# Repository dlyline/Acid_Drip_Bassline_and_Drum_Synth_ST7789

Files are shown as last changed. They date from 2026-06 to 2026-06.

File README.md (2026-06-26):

# Acid Drip - Bassline Synth & Drum Machine

<p align="center">
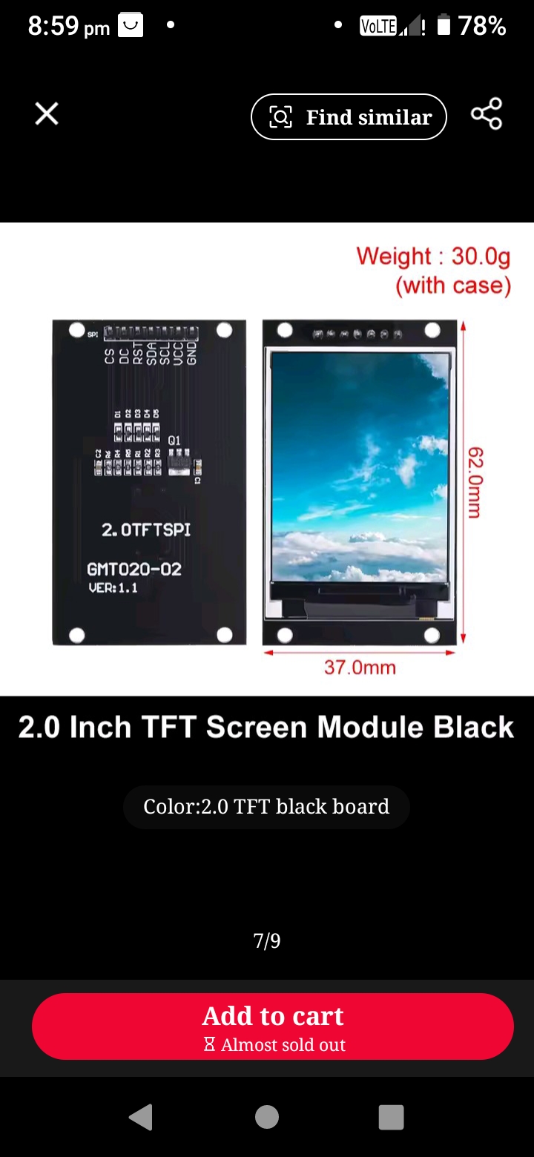
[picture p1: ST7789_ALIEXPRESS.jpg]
TFT
  
  &nbsp;
  DIY
</p>

Youtube Video (click the image) - Acid Drip Demo (https://youtu.be/anotb2mvv04) 

An RP2040-based acid bassline synthesizer and drum machine built on the Mozzi audio library. Two instruments in one device, a 16-step acid sequencer and a 16-pattern drum groove box running simultaneously on dual cores with a 320x240 ILI9341 TFT display and 16 Cherry MX pads.

NOTE: the images of the synth are V1. V2 is what I have provided in this repo and looks a little different (extra pot for mix added)

  

<p align="center">
  Acid Drip - angle view on cyan
  &nbsp;
  Acid Drip - front view on orange
  &nbsp;
  Acid Drip - perspective view on green
</p>

---

## Hardware

| Component | Detail |
|---|---|
| MCU | RP2040 (Raspberry Pi Pico or equivalent) |
| Display | ILI9341 320x240 TFT |
| Pads | 16x Cherry MX switches (2 rows of 8) |
| Pots | 3x analog (CUT, RES, DECAY) |
| Audio out (acid) | GP15 -> 100R + 10nF RC filter -> 3.5mm jack |
| Audio out (drums) | GP2 -> 470R resistor -> 3.5mm jack |
| Sync in | GP2 (hardware SPDT switch selects drum audio OR sync input) |

### Wiring

```
TFT   : SCK=GP6  SDA=GP7  RST=GP8  DC=GP10  CS=GP13
Pots  : CUT=GP26  RES=GP28  DCY=GP27
Sync  : IN=GP2
Audio : Acid=GP15   Drums=GP2

Top row pads (steps 1-8):
  GP14=pad1  GP12=pad2  GP11=pad3  GP16=pad4
  GP17=pad5  GP19=pad6  GP20=pad7  GP21=pad8

Bottom row pads (steps 9-16 / FUNC select):
  GP0=pad9   GP1=pad10  GP3=pad11  GP4=pad12
  GP5=pad13  GP9=pad14  GP18=pad15 GP22=pad16
```

---

## Dependencies

Install via Arduino Library Manager:

- **Mozzi** (audio synthesis engine)
- **Adafruit GFX**
- **Adafruit ILI9341**

Board package: **Raspberry Pi Pico/RP2040** (Earle Philhower core)

---

## Files

| File | Description |
|---|---|
| `Acid_Drip_V4.ino` | Main sketch -- acid synth engine, sequencer, UI |
| `BeatMachine2.ino` | Drum machine tab -- DrumKid engine, 8 instruments |
| `beats.h` | 16 preset drum patterns (techno, house, hip-hop, etc.) |
| `sample0-7.h` | Drum samples stored as int8 arrays in flash (PROGMEM) |

---

## Acid Synthesizer

### Pad Layout

```
+---------+---------+---------+---------+---------+---------+---------+---------+
|    1    |    2    |    3    |    4    |    5    |    6    |    7    |    8    |
|  step   |  step   |  step   |  step   |  step   |  step   |  step   |  step   |
|    1    |    2    |    3    |    4    |    5    |    6    |    7    |    8    |
+---------+---------+---------+---------+---------+---------+---------+---------+
|    9    |   10    |   11    |   12    |   13    |   14    |   15    |   16    |
|   KEY   |  RIFF   |  SOUND  |  WALK   |   FX    |  TEMPO  |  PLEN   |  PAT>  |
+---------+---------+---------+---------+---------+---------+---------+---------+
  (bottom row labels show only in FUNC mode)
```

### Step Editing

| Action | Result |
|---|---|
| Short press a pad | Toggle step on/off |
| Long press x1 | Toggle accent |
| Long press x2 | Toggle glide |
| Hold pad + turn CUT pot | Set step note (scale-quantised) |

### Chords

| Chord | Action |
|---|---|
| Pads 1+2 | Play / Stop |
| Pads 1+2 (hold 2s) | Factory reset |
| Pads 7+8 | Enter / exit FUNC mode |
| Pads 9+10 | Switch between acid synth and drum machine |
| Pads 11+12+13+14 (hold 1s) | Toggle Acid Walks easter egg |
| Pads 15+16 (hold 1s) | Toggle Accent Edit mode |

### Save / Load (hold pads 7+8)

- **Tap** pads 3/4/5/6 -> load from slot 1/2/3/4
- **Hold** pads 3/4/5/6 for 1 second -> save to slot 1/2/3/4
- Slot status shown top-right (yellow dot = saved, grey = empty)

### FUNC Mode (enter with pads 7+8)

| Pad | Function | Options |
|-----|---|---|
| 9 | KEY | Root note: C D Eb F G Ab Bb B |
| 10 | RIFF | Load preset riff pattern: DFLT / SQNCE / FUNK / MINI / JUMP / RAVE / SYNC / DARK |
| 11 | SOUND | Synth voice: SAW / SQR / SINE / PWM / CSAW / CSQR / CSIN / SUBSQ |
| 12 | WALK | Note walk: OFF / 4TH / OCTWAVE / 5TH / BOUNCE / MIN3RD / VAMP3 / RANDOM |
| 13 | FX | Enter FX assign sub-mode |
| 14 | TEMPO | Preset BPM: 100/110/120/128/133/138/145/160 -- or tap repeatedly for tap tempo |
| 15 | PLEN | Pattern length: 1 / 2 / 3 / 4 / 6 / 8 / 12 / 16 |
| 16 | PAT> | Playback order: FWD / CW / ALT / REV / SKIP2 / SKIP3 / PING / RND |

> Note: there is currently no live scale-type or octave selector -- `seq.scale`/`seq.octave` are only set when loading a saved patch slot.

### FX Assign (FUNC -> pad 13)

1. Press a top-row pad to select an effect:
   `None / Oct Up / Retrigger / Stutter / Maj Step / Min Step / Dom7 Step / Dim Step`
2. Press any pad 1-16 to assign that effect to that step.
3. Tap the selected FX pad again to deselect.
4. Long-hold pad 1 to clear all step effects.
5. Pads 7+8 to exit back to main screen.

### Accent Edit

Hold **pads 15+16** for 1 second to enter Accent Edit mode. The three pots are repurposed to tune the accent envelope itself rather than the live filter:

| Pot | Function |
|-----|---|
| CUT | Accent peak cutoff boost (brightness added on accented steps) |
| RES | Accent peak resonance boost |
| DCY | Accent envelope decay-time multiplier |

Normal CUT/RES/DCY values freeze at their last setting while tuning, so the bassline's base tone doesn't change -- only accented steps reflect the new values, live, as you turn the pots. Hold pads 15+16 again to exit; the tuned values are saved to EEPROM automatically and persist across power cycles until changed again.

### Acid Walks (Easter Egg)

Hold **pads 11+12+13+14** for 1 second to toggle a hidden mode with 8 preset patterns inspired by classic acid/house tracks, each pre-loaded with its own key, tempo, length and sound. Select a pattern with pads 1-8. FUNC mode, FX assignment and drum mode all continue to work normally while active. Hold the same 4-pad chord again to exit.

---

## Beat Machine

Switch between acid and drum mode by pressing **pads 9+10 simultaneously**. The sequencer state is preserved when switching.

### Drum Instruments (8 tracks)

| Pad | Instrument |
|-----|---|
| 1 | Kick |
| 2 | Hi-hat (closed) |
| 3 | Snare |
| 4 | Rim |
| 5 | Tom |
| 6 | Bass 2 |
| 7 | Clap |
| 8 | Open hat |

### Pattern Selection

Short-tap any pad (1-16) to load that beat pattern. The current pattern name and number are shown on the display. Pads 1-5 double as drum edit pads (see below) -- a short tap selects the pattern, a long hold enters drum editing.

### Per-Drum Editing

Hold any of pads 1-5 (kick/hat/snare/rim/tom) and turn the pots:

- **CUT** -> pitch (exponential, pot centre = natural speed, each 64 units = one octave)
- **RES** -> decay length (exponential envelope from a 4ms blip to full sample tail)
- **DCY** -> volume

Pot pickup prevents value jumps when grabbing a control -- each pot only responds once it has been physically moved past its position at the moment the pad was grabbed. Per-drum settings reset on pattern change and are saved with slots.

> Bass 2, Clap, and Open Hat (pads 6-8) cannot be edited via hold+pot. Pattern selection is their only pad function.

### Beat Machine FUNC Mode (pads 7+8)

| Label | Function | Detail |
|---|---|---|
| PTCH | Global pitch | Transposes all drums together; stacks on top of per-drum pitch |
| DRIV | Drive / saturation | Exponential pre-gain into a hard-knee saturator; top of the knob also adds bit crush |
| FILT | Bipolar DJ filter | Centre = bypass; below centre = lowpass sweep; above centre = highpass sweep |
| CHNC | Chance | Centre = as-is; below = thins existing hits (anchors held solid); above = adds ghost hits on empty steps |
| HMNZ | Humanize | Adds random velocity spread and per-hit micro-timing jitter; centre = robotic |
| SWNG | Swing | Delays odd 16th steps up to 60% of the step interval for a swung feel |
| ACNT | Accent depth | Centre = flat; above centre = on-beat emphasis; below centre = off-beat (pushed) emphasis |
| FILL | Procedural fill engine | See Fill Engine below |

All FUNC parameters except FILT and CHNC are saved with slots.

### Fill Engine (FUNC -> FILL)

The fill engine takes over the last few steps before a pattern boundary with a procedurally generated build, then lands on beat 1 with a kick and open hat.

**Pads 1-4** set the fill frequency:

| Pad | Label | Behaviour |
|-----|---|---|
| 1 | OFF | No fills |
| 2 | 1 BAR | Fill every 16 steps (4 steps long) |
| 3 | 2 BAR | Fill every 32 steps (6 steps long) |
| 4 | 4 BAR | Fill every 64 steps (8 steps long, half a bar) |

**Pads 5-8** set the fill type:

| Pad | Label | Behaviour |
|-----|---|---|
| 5 | HATS | Closed-hat build opening to an open hat on the tail; kick holds the floor |
| 6 | CLAP | Clap build over a steady half-time kick |
| 7 | SNARE | Flat snare rush with no kick; the landing slams |
| 8 | KIT | Descending tom for the first 70% of the window, then snare into the landing; KIT also adds a clap on the "1" |

> Pads 7 and 8 are also the FUNC-exit chord. SNARE and KIT selections register on release so the exit gesture takes priority.

**Editing the fill sound:** while in the FILL slot, the three pots control the lead voice's own pitch, decay length, and volume independently of the pattern's drum settings. These are saved with slots.

Density accelerates into the landing: the final quarter of the fill window schedules additional 32nd-note in-between hits so the build feels like it rushes into the "1".

### Preset Patterns

16 patterns selectable from the pad grid:

| # | Short name | Full name |
|---|---|---|
| 1 | BASC | BASIC |
| 2 | HOUS | HOUSE |
| 3 | TECH | TECHNO |
| 4 | ACID | ACID TRACK |
| 5 | HSOC | HI STATE |
| 6 | FUNK | FUNKY |
| 7 | SWNG | SWING |
| 8 | BKBT | BREAKBEAT |
| 9 | MINM | MINIMAL |
| 10 | LATN | LATIN |
| 11 | PCFC | PACIFIC ST |
| 12 | BLMN | BLUE MONDAY |
| 13 | DNBT | DRUM N BASS |
| 14 | VOOD | VOODOO RAY |
| 15 | GBLD | BUILD DOWN |
| 16 | JACK | JACK BEAT |

### Save / Load (drum mode)

Same gesture as the acid synth: hold pads 7+8, then tap pads 3-6 to load from slot 1-4 or hold pads 3-6 for one second to save. Per-drum pitch/length/volume, global FUNC parameters, tempo, swing, fill settings, and the selected pattern are all stored.

---

## Sync In / Drum Mode (GP2)

GP2 is shared between drum audio output and external sync clock input. A physical **SPDT switch on the PCB** routes the pin to either function.

**Boot detection selects the mode:**

- **Drum mode (default):** GP2 is claimed by PWMAudio DMA and outputs drum audio. Switch in the DRUMS position.
- **Sync In mode:** Hold **pad 14** at power-on. GP2 is configured as a digital input and listens for an external clock pulse. Switch in the SYNC position.

A cyan "SYNC IN ACTIVE" message is shown briefly after boot when sync mode is detected.

> The switch position and held pad must match. If the switch is in SYNC position but the device boots into drum mode, GP2 will try to drive audio into the sync signal line.

---

## Architecture Notes

The firmware runs on both RP2040 cores:

- **Core 0** -- Mozzi audio engine (acid synthesis + drum mixing), pad scanning, sequencer logic
- **Core 1** -- TFT display rendering, drum sample buffer filling (via `bmFillDrumBuffer`)

The two cores communicate via the RP2040 inter-core FIFO. All SPI/TFT calls happen exclusively on core 1.

The drum clock is driven directly by the acid sequencer's `advanceStep()` call rather than an independent timer. This guarantees zero drift between the two engines at all tempos and pattern lengths.

The drum audio path on GP2 uses a separate `PWMAudio` DMA instance at 488kHz carrier (versus Mozzi's 48kHz on GP15). This prevents carrier-frequency beating between the two audio outputs that would otherwise cause the acid synth to sound quieter when drums are playing.

---

## Credits

- Acid synthesis engine adapted from *Badass Bass*  https://www.youtube.com/watch?v=MvDILHYImc4
- Drum engine adapted from **DrumKid** by Matt Bradshaw  https://www.youtube.com/watch?v=509iZGjnVhM
- Built with the [Mozzi](https://sensorium.github.io/Mozzi/) audio library
- Hardware design and firmware by Marcus ([lonesoulsurfer](https://github.com/lonesoulsurfer))

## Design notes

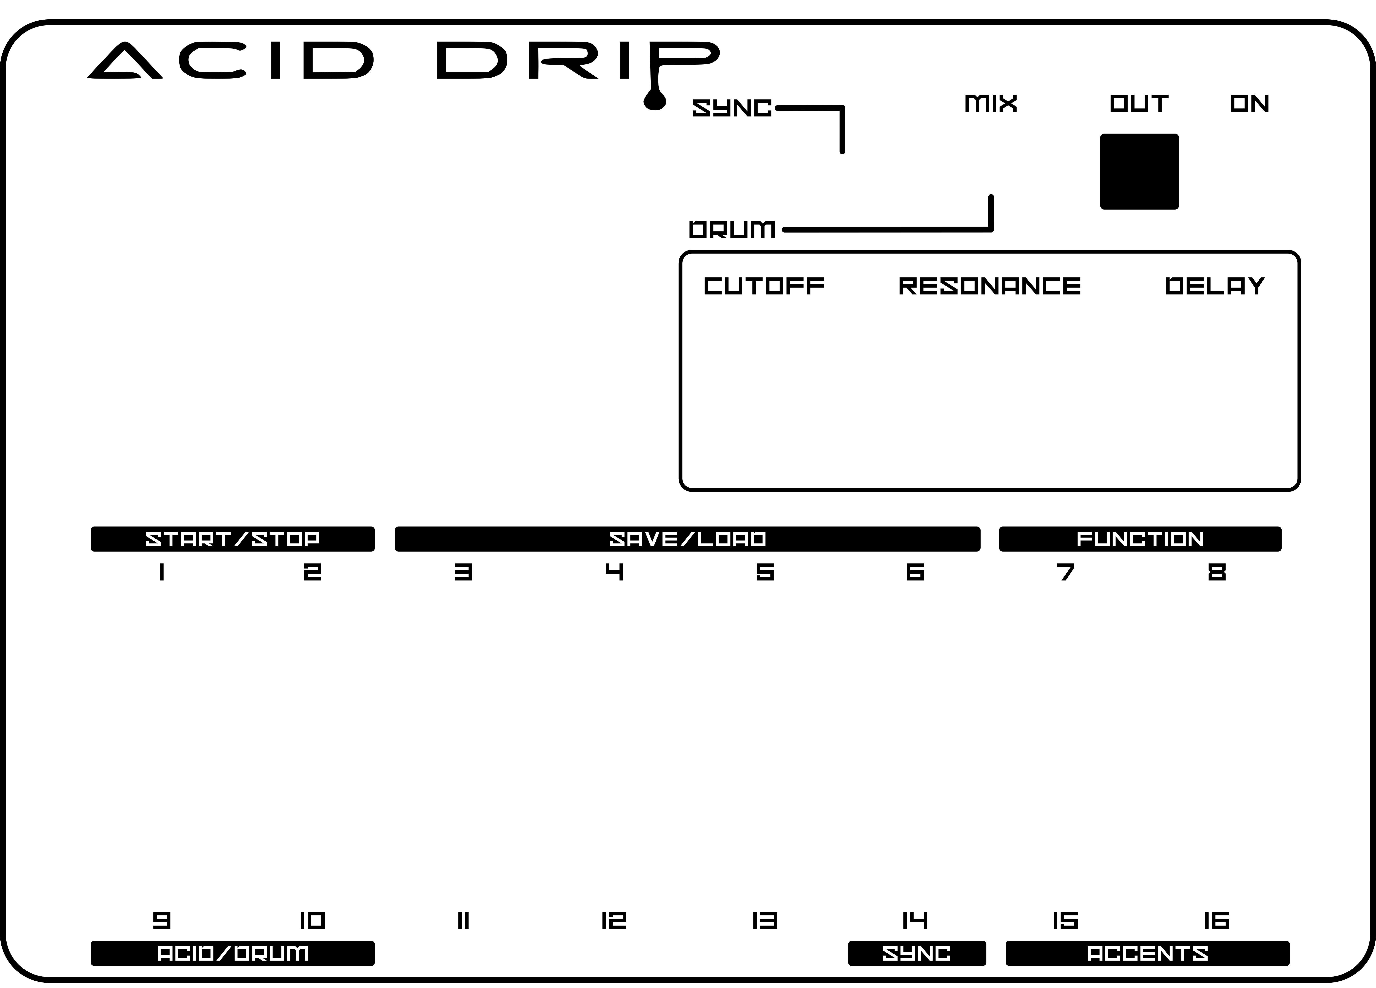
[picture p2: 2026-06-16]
Front Panel Design/Acid - Front Panel - Inkscape.png

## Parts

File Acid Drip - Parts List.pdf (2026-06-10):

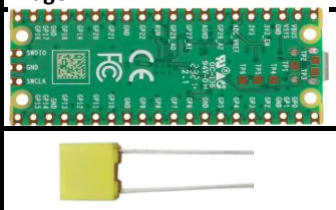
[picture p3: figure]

Part | Reference Qty Type Value Link | Image
RaspberryPi Pico | You want the board that A1 1 has 3 Analog pins (GP26, Link (https://www.aliexpress.com/w/wholesale-raspberry-pi-pico.html?g=y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) GP27 & GP28)
Capacitor | C7 1 10nf Polypropylene Link (https://www.aliexpress.com/item/1005003580268418.html) C1,C2,C4 3 100nf
| C3,C5,C6 3 100uf Electrolytic Link (https://www.aliexpress.com/w/wholesale-Electrolytic-capacitor-radial.html?spm=a2g0o.detail.search.0) C9 1 1000uf

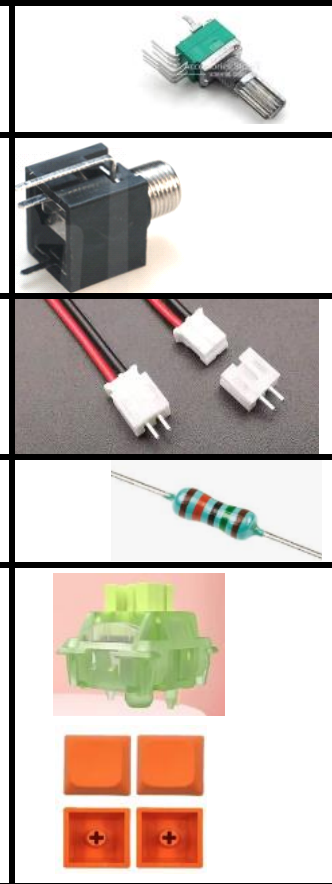
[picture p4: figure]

Potentiometer | Cutoff1, Delay1, 3 10K Resonance1 9mm verticle Link (https://www.aliexpress.com/item/1005006008223062.html) level1 1 50K
Audio Jack Socket | J1, J2 2 PJ-301M / PJ301M 3.5mm Link (https://www.aliexpress.com/item/1005004864182675.html?curPageLogUid=0zQE4k2UhBlQ)
JST Connector | PH 2.0MM XH 2.54MM JST J3 1 2 pin Link (https://www.aliexpress.com/item/1005009732772187.html?curPageLogUid=asoqkGrrPVM0) 2Pin
Resistor | R1 1 3.3K Metal Film Link (https://www.aliexpress.com/item/1005005975043598.html) R3 1 10K
Switch | 16 Cherry MX Link (https://www.aliexpress.com/item/1005007307636103.html?curPageLogUid=zbi4aXwEf3vn) SW1,SW2,SW3,SW4,SW 5,SW6,SW7,SW8,SW9,S W10,SW11,SW12,SW13 ,SW14,SW15,SW16 16 Cherry Keycaps Link (https://www.aliexpress.com/w/wholesale-Key-Caps-for-Cherry-Mx-Switches.html)
| SW17,SW18 2 Toggle switch MTS_102 Link
TFT Screen 2.8" | U1 1 ILI9341 Link (https://www.aliexpress.com/item/1005011840876662.html)
Spacers | M2 assorted - Nylon Link (https://www.aliexpress.com/item/32862529967.html)
Screws | M2 - Hex Head Black 2500P Link (https://www.aliexpress.com/item/1005007159750547.html)
Mobile or 18650 battery | 1 EB494358VU 3.7V Link (https://www.aliexpress.com/item/1005009069874084.html?src=google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)

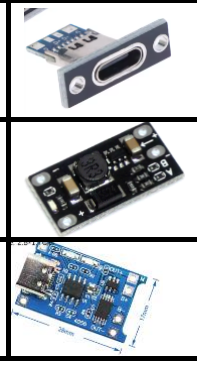
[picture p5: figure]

USB C Socket | Type-C USB Jack 3.1 Type-1 C 2Pin/4Pin Link (https://www.aliexpress.com/item/1005006485428578.html)
Voltage Regulator | DC-DC Boost Step Up 1 Link (https://www.aliexpress.com/item/1005001276257282.html?curPageLogUid=cH4A9dRXs1FV) Converter
Charging Module | 1 TP4056 Link (https://www.aliexpress.com/item/1005007543796930.html?curPageLogUid=mDOVHyZAyjIQ)

POWER 5V - PARTS REQUIRED

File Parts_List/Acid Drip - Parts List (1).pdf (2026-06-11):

Part | Reference Qty Type Value Link | Image
RaspberryPi Pico | You want the board that A1 1 has 3 Analog pins (GP26, Link (https://www.aliexpress.com/w/wholesale-raspberry-pi-pico.html?g=y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) GP27 & GP28)
Capacitor | C7 1 10nf Polypropylene Link (https://www.aliexpress.com/item/1005003580268418.html) C1,C2,C4 3 100nf
| C3,C5,C6 3 100uf Electrolytic Link (https://www.aliexpress.com/w/wholesale-Electrolytic-capacitor-radial.html?spm=a2g0o.detail.search.0) C9 1 1000uf

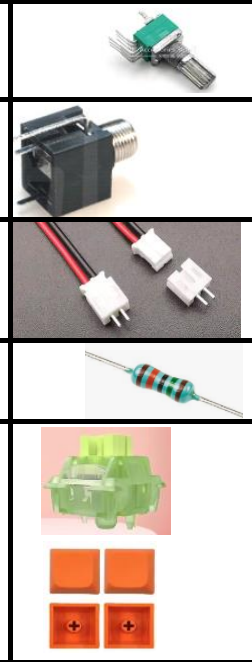
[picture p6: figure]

Potentiometer | Cutoff, Delay, Resonance, level 4 9mm verticle 10K Link (https://www.aliexpress.com/item/1005006008223062.html)
Audio Jack Socket | J1, J2 2 PJ-301M / PJ301M 3.5mm Link (https://www.aliexpress.com/item/1005004864182675.html?curPageLogUid=0zQE4k2UhBlQ)
JST Connector | PH 2.0MM XH 2.54MM JST J3 1 2 pin Link (https://www.aliexpress.com/item/1005009732772187.html?curPageLogUid=asoqkGrrPVM0) 2Pin
Resistor | R1 1 3.3K Metal Film Link (https://www.aliexpress.com/item/1005005975043598.html) R3 1 10K
Switch | 16 Cherry MX Link (https://www.aliexpress.com/item/1005007307636103.html?curPageLogUid=zbi4aXwEf3vn) SW1,SW2,SW3,SW4,SW 5,SW6,SW7,SW8,SW9,S W10,SW11,SW12,SW13 ,SW14,SW15,SW16 16 Cherry Keycaps Link (https://www.aliexpress.com/w/wholesale-Key-Caps-for-Cherry-Mx-Switches.html)

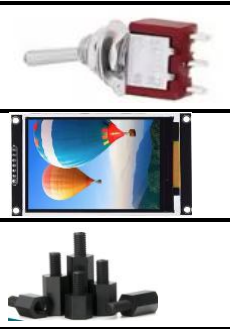
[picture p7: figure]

| SW17,SW18 2 Toggle switch MTS_102 Link
TFT Screen 2.8" | U1 1 ILI9341 Link (https://www.aliexpress.com/item/1005011840876662.html)
Spacers | M2 assorted - Nylon Link (https://www.aliexpress.com/item/32862529967.html)
Screws | M2 - Hex Head Black 2500P Link (https://www.aliexpress.com/item/1005007159750547.html)
Mobile or 18650 battery | 1 EB494358VU 3.7V Link (https://www.aliexpress.com/item/1005009069874084.html?src=google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)
USB C Socket | Type-C USB Jack 3.1 Type-1 C 2Pin/4Pin Link (https://www.aliexpress.com/item/1005006485428578.html)
Voltage Regulator | DC-DC Boost Step Up 1 Link (https://www.aliexpress.com/item/1005001276257282.html?curPageLogUid=cH4A9dRXs1FV) Converter
Charging Module | 1 TP4056 Link (https://www.aliexpress.com/item/1005007543796930.html?curPageLogUid=mDOVHyZAyjIQ)

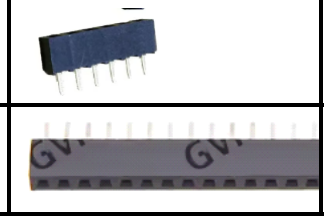
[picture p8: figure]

Header Pins Short Profile | 1 7P 2.54mm PH5 Link (https://www.aliexpress.com/item/1005004122312694.html)
Header Pins -female | 2 20P Link (https://www.aliexpress.com/w/wholesale-female-header-pins.html?spm=a2g0o.detail.search.0)

POWER 5V - PARTS REQUIRED

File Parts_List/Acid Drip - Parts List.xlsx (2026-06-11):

Part | Reference | Qty | Type | Value | Link | Image
RaspberryPi Pico | A1 | 1 | You want the board that has 3 Analog pins (GP26, GP27 & GP28) |  | Link (https://www.aliexpress.com/w/wholesale-raspberry-pi-pico.html?g=y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)
Capacitor | C7 | 1 | Polypropylene | 10nf | Link (https://www.aliexpress.com/item/1005003580268418.html)
 | C1,C2,C4 | 3 |  | 100nf
 | C3,C5,C6 | 3 | Electrolytic | 100uf | Link (https://www.aliexpress.com/w/wholesale-Electrolytic-capacitor-radial.html?spm=a2g0o.detail.search.0)
 | C9 | 1 |  | 1000uf
Potentiometer | Cutoff, Delay, Resonance, level | 4 | 9mm verticle | 10K | Link (https://www.aliexpress.com/item/1005006008223062.html)
Audio Jack Socket | J1, J2 | 2 | PJ-301M / PJ301M | 3.5mm | Link (https://www.aliexpress.com/item/1005004864182675.html?curPageLogUid=0zQE4k2UhBlQ) | #VALUE!
JST Connector | J3 | 1 | PH 2.0MM XH 2.54MM JST 2Pin | 2 pin | Link (https://www.aliexpress.com/item/1005009732772187.html?curPageLogUid=asoqkGrrPVM0) | #VALUE!
Resistor | R1 | 1 | Metal Film | 3.3K | Link (https://www.aliexpress.com/item/1005005975043598.html)
 | R3 | 1 |  | 10K
Switch | SW1,SW2,SW3,SW4,SW5,SW6,SW7,SW8,SW9,SW10,SW11,SW12,SW13,SW14,SW15,SW16 | 16 | Cherry MX |  | Link (https://www.aliexpress.com/item/1005007307636103.html?curPageLogUid=zbi4aXwEf3vn)
 |  | 16 | Cherry Keycaps |  | Link (https://www.aliexpress.com/w/wholesale-Key-Caps-for-Cherry-Mx-Switches.html)
 | SW17,SW18 | 2 | Toggle switch | MTS_102 | Link
TFT Screen 2.8" | U1 | 1 | ILI9341 |  | Link (https://www.aliexpress.com/item/1005011840876662.html)
Spacers |  |  | M2 assorted - Nylon |  | Link (https://www.aliexpress.com/item/32862529967.html)
Screws |  |  | M2 - Hex Head | Black 2500P | Link (https://www.aliexpress.com/item/1005007159750547.html)
POWER 5V - PARTS REQUIRED
Mobile or 18650 battery |  | 1 | EB494358VU | 3.7V | Link (https://www.aliexpress.com/item/1005009069874084.html?src=google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)
USB C Socket |  | 1 | Type-C USB Jack 3.1 Type-C 2Pin/4Pin |  | Link (https://www.aliexpress.com/item/1005006485428578.html)
Voltage Regulator |  | 1 | DC-DC Boost Step Up Converter |  | Link (https://www.aliexpress.com/item/1005001276257282.html?curPageLogUid=cH4A9dRXs1FV) | #VALUE!
Charging Module |  | 1 | TP4056 |  | Link (https://www.aliexpress.com/item/1005007543796930.html?curPageLogUid=mDOVHyZAyjIQ) | #VALUE!
Header Pins Short Profile |  | 1 | 7P | 2.54mm PH5 | Link (https://www.aliexpress.com/item/1005004122312694.html)
Header Pins - female |  | 2 | 20P |  | Link (https://www.aliexpress.com/w/wholesale-female-header-pins.html?spm=a2g0o.detail.search.0) | #VALUE!

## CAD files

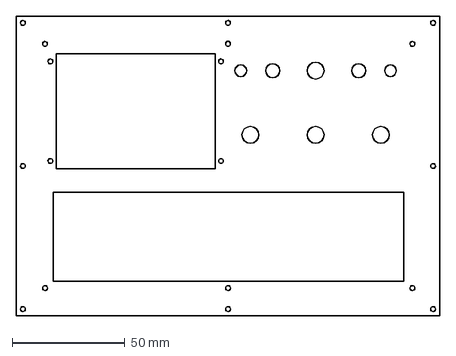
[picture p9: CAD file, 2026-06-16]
Front Panel Design/front panel - Fusion.dxf
188.0 x 133.0 mm

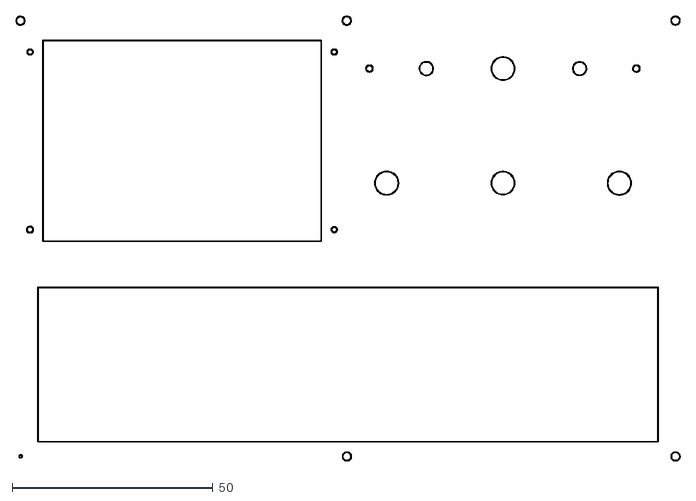
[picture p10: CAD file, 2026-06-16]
Front Panel Design/PCB/Acid_Synth-User_1.dxf
165.2 x 110.7

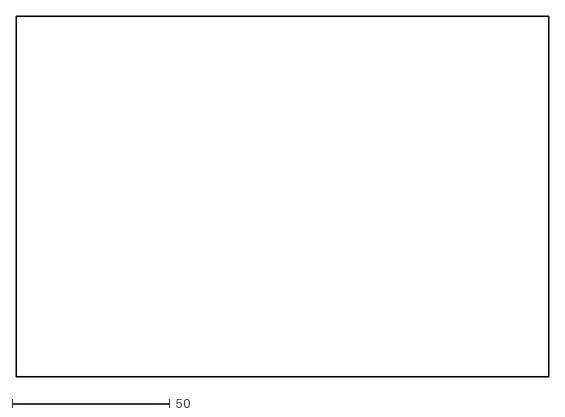
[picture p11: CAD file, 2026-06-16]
Front Panel Design/PCB/Acid_Synth-Edge_Cuts.dxf
169.0 x 114.5

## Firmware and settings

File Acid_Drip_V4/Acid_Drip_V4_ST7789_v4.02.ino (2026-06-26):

/*
 * =====================================================================
 *              Acid Drip - RP2040 Acid Bassline Synthesizer
 *              Synthesis engine ported from reference "Badass Bass"
 * =====================================================================
 *
 * BUTTON LAYOUT (2 rows of 8 pads):
 *
 *   ┌─────┬─────┬─────┬─────┬─────┬─────┬──────┬──────┐
 *   │  1  │  2  │  3  │  4  │  5  │  6  │  7   │  8   │
 *   │step │step │step │step │step │step │step  │step  │
 *   │ 1   │ 2   │ 3   │ 4   │ 5   │ 6   │ 7    │ 8    │
 *   ├─────┼─────┼─────┼─────┼─────┼─────┼──────┼──────┤
 *   │  9  │ 10  │ 11  │ 12  │ 13  │ 14  │  15  │  16  │
 *   │KEY  │RIFF │SOUND│WALK │ FX  │TEMPO│PLEN  │PAT>  │
 *   └─────┴─────┴─────┴─────┴─────┴─────┴──────┴──────┘
 *   (bottom row labels only visible in FUNC mode)
 *
 * PAD FUNCTIONS (normal mode):
 *   Short press         : Toggle step on/off
 *   Long press ×1       : Toggle accent
 *   Long press ×2       : Toggle glide
 *   Hold + CUT pot      : Set step note (scale-quantised)
 *   All 16 pads are full steps — no dedicated buttons
 *
 * CHORD: PLAY (pads 1+2 simultaneously):
 *   Start / Stop sequencer
 *   Long hold (1s+)     : Factory reset
 *
 * CHORD: FUNC (pads 7+8 simultaneously):
 *   Toggle FUNC mode on/off
 *   Exits FX assign sub-mode if active
 *
 * SAVE / LOAD (while holding pads 7+8):
 *   Tap pad 3/4/5/6     : Load patch from slot 1/2/3/4
 *   Hold pad 3/4/5/6    : Save patch to slot 1/2/3/4 (1 second hold)
 *   Slot status shown as dots top-right of screen (yellow=saved, grey=empty)
 *
 * FUNC MODE (pads 7+8 to enter/exit):
 *   Bottom row pads 9-16 select a function (labels shown on screen):
 *     Pad 9  = KEY    — top row pads 1-8 select root note (C D Eb F G Ab Bb B)
 *     Pad 10 = RIFF   — pads 1-8 select preset riff pattern (DFLT/SQNCE/FUNK/MINI/JUMP/RAVE/SYNC/DARK)
 *     Pad 11 = SOUND  — top row pads 1-8 select synth voice
 *     Pad 12 = WALK   — top row pads 1-8 select note walk mode
 *                        p1=OFF  p2=4TH    p3=OCTWAVE p4=5TH
 *                        p5=BOUNCE  p6=MIN3RD  p7=VAMP3  p8=RANDOM
 *     Pad 13 = FX     — enters FX ASSIGN sub-mode
 *     Pad 14 = TEMPO  — top row pads 1-8 select preset BPM (100/110/120/128/133/138/145/160)
 *                        tap TEMPO pad repeatedly to set BPM by tap-tempo
 *     Pad 15 = PLEN   — top row pads 1-8 set length 1-8
 *                        bottom row pads 9-16 set length 9-16
 *     Pad 16 = PAT>   — top row pads 1-8 select pattern play mode:
 *                        p1=FWD  p2=CW (fwd then rev)  p3=ALT (odd/even)  p4=REV
 *                        p5=SKIP2 (every 2nd)  p6=SKIP3 (every 3rd)  p7=PING  p8=RND
 *
 * FX ASSIGN SUB-MODE (FUNC → pad 13):
 *   Phase 1: press top-row pads 1-8 to select an effect:
 *     Pad 1=None  Pad 2=Oct Up  Pad 3=Retrigger  Pad 4=Stutter
 *     Pad 5=Maj Step  Pad 6=Min Step  Pad 7=Dom7 Step  Pad 8=Dim Step
 *   Phase 2: press any pad 1-16 to assign that effect to that step
 *   Tap selected FX pad again to deselect
 *   Long-hold pad 1 = clear all step effects
 *   Pads 7+8 chord = exit FX assign to main screen
 *
 * EASTER EGG: ACID WALKS (pads 11+12+13+14, hold 1s):
 *   Toggles a hidden bank of 8 patterns inspired by classic acid/house
 *   tracks, each with its own preset key/tempo/length/sound.
 *   Pads 1-8 select a pattern. FUNC mode, FX assign, and drum mode all
 *   continue to work normally while active. Hold the same chord again
 *   to exit back to the normal pattern.
 *
 * ACCENT EDIT (pads 15+16, hold 1s):
 *   Toggles a mode where CUT/RES/DCY tune the accent envelope itself
 *   instead of the live filter:
 *     CUT = accent peak cutoff boost   RES = accent peak resonance boost
 *     DCY = accent decay-time (CCW=short/snappy, CW=long/dramatic)
 *   Normal CUT/RES/DCY values freeze while tuning. Hold the chord again
 *   to exit — settings save to EEPROM automatically and persist across
 *   power cycles until changed again.
 *
 * WIRING:
 *   TFT   : SCK=GP6, SDA=GP7, RST=GP8, DC=GP10, CS=GP13
 *   Pots  : CUT=GP26, RES=GP28, DCY=GP27
 *   Sync  : IN=GP2 (hold pad 14 at power-on to boot into Sync In mode)
 *   Audio : GP15 (100R + 10nF RC filter to output jack)
 *
 *   Pads (top row, steps 1-8 / FUNC apply):
 *     GP14=pad1  GP12=pad2  GP11=pad3  GP16=pad4
 *     GP17=pad5  GP19=pad6  GP20=pad7  GP21=pad8
 *
 *   Pads (bottom row, steps 9-16 / FUNC select):
 *     GP0=pad9   GP1=pad10  GP3=pad11  GP4=pad12
 *     GP5=pad13  GP9=pad14  GP18=pad15 GP22=pad16
 *
 * =====================================================================
 */

// =====================================================================
// MOZZI CONFIG - must precede all includes
// =====================================================================
#include "MozziConfigValues.h"
#define MOZZI_AUDIO_MODE     MOZZI_OUTPUT_PWM
#define MOZZI_ANALOG_READ    MOZZI_ANALOG_READ_NONE
#define MOZZI_AUDIO_PIN_1    15
#define MOZZI_AUDIO_RATE     16384
#define MOZZI_CONTROL_RATE   256

#include <Mozzi.h>
#include <SPI.h>
#include <Adafruit_GFX.h>
#include <Adafruit_ST7789.h>
#include <EEPROM.h>

// ── Beat Machine 2 — forward declarations ────────────────────────────
extern bool   bmMode;
extern bool   bmFullDirty;
extern void   bmInit();
extern void   bmUpdateControl();
extern void   bmDoDraw();
extern void   bmStartAudio();
extern void   bmClearPadState();
extern bool   bmPotLocked;
extern uint8_t bmPotPickup;
extern void     bmTriggerStep(uint8_t step);
extern byte     bmStepDiv;
extern byte     bmPulseNum;
extern uint16_t bmStepNum;
extern byte     bmDrumPos;
extern bool   bmPlaying;
extern bool   bmPlayChanged;
extern void   bmFillDrumBuffer();
extern void   bmDrawDrumFlash();
extern uint32_t bmLastFlashDraw;
extern float    bmStoredTempo;
extern bool     bmPChord[16];
extern bool     bmPState[16];

bool     bmModeArmed = false;
uint32_t bmModeArmMs = 0;
#define BM_SW_A  8   // pad 9 (index 8) — mode switch pad A
#define BM_SW_B  9   // pad 10 (index 9) — mode switch pad B
bool     bmAcidWasRunning = false;  // remember acid state across mode switch
bool     bmDrumsWerePlaying = false; // remember drum state when acid stop pressed

// Easter egg: hold pads 11+12+13+14 (indices 10-13) together for ~1s to
// toggle "Acid Walks" — a value strip of 8 classic-acid-inspired patterns.
#define WALK_PAD_A 10  // pad 11
#define WALK_PAD_B 11  // pad 12
#define WALK_PAD_C 12  // pad 13
#define WALK_PAD_D 13  // pad 14
#define WALK_HOLD_MS 1000
bool     walksMode    = false;  // true while the Acid Walks value strip is shown
bool     walksArmed   = false;  // chord held, waiting for WALK_HOLD_MS
uint32_t walksArmMs   = 0;
uint8_t  curWalk      = 0;      // currently-loaded Acid Walks pattern index

// ACCENT EDIT: hold pads 15+16 (indices 14-15) together for ~1s to toggle
// a mode where the CUT/RES/DECAY pots tune the accent envelope itself
// (peak cutoff boost, peak resonance boost, and decay-time multiplier)
// instead of the live filter. Values are saved to EEPROM on exit so the
// "locked in" accent sound persists across power cycles.
#define ACCENT_PAD_A 14  // pad 15
#define ACCENT_PAD_B 15  // pad 16
#define ACCENT_HOLD_MS 1000
bool     accentEditMode  = false;  // true while CUT/RES/DECAY pots tune the accent envelope
bool     accentEditArmed = false;  // chord held, waiting for ACCENT_HOLD_MS
uint32_t accentEditArmMs = 0;
int16_t  accentEnvCutoff = 90;   // accent peak cutoff boost (0-255) — replaces hardcoded 90
int16_t  accentEnvRes    = 90;   // accent peak resonance boost (0-400) — replaces hardcoded 90
int16_t  accentDecayDiv  = 5;    // accent envelope decay divisor (1-10) — replaces hardcoded 5



// =====================================================================
// PINS
// =====================================================================
#define TFT_CS    13
#define TFT_RST    8
#define TFT_DC    10
#define TFT_MOSI   7
#define TFT_SCK    6
#define POT_CUT   26
#define POT_RES   28
#define POT_DECAY 27
#define SYNC_IN    2

// 16 pads — top row (steps 1-8): applies FUNC values / FX assign phase 1+2
//           bottom row (steps 9-16): selects FUNC function in FUNC mode
// Chord: pads 1+2 (indices 0+1) = PLAY/STOP, pads 7+8 (indices 6+7) = FUNC toggle
const uint8_t PAD_PINS[16] = {
  14,12,11,16,17,19,20,21,   // pads 1-8  (steps 1-8,  top row) — pad1=GP14, pad3=GP11 (swapped)
   0, 1, 3, 4, 5, 9,18,22    // pads 9-16 (steps 9-16, bottom row)
};

#define PAD_PLAY_A  0   // pads 1+2 pressed together = PLAY/STOP
#define PAD_PLAY_B  1
#define PAD_FUNC_A  6   // pads 7+8 pressed together = FUNC toggle
#define PAD_FUNC_B  7

// =====================================================================
// DISPLAY
// =====================================================================
#define SW 320
#define SH 240

// Colour palette (RGB565)
#define C_BG    0x0000
#define C_WHT   0xFFFF
#define C_RED   0xF800
#define C_GRN   0x07E0
#define C_YEL   0xFFE0
#define C_CYN   0x07FF
#define C_ORG   0xFC60
#define C_DGR   0x4208
#define C_MGR   0x8410
#define C_BLU   0x001F
#define C_MGN   0xF81F  // magenta — accent indicator

// Step-grid colors (303-style warm amber, replacing plain greys for step cells)
#define C_AMB   0xFC60  // orange — active note bar fill, cursor cell background (matches title 'I')
#define C_AMBBG 0x3922  // dark amber-brown — active step cell background (non-cursor)
#define C_AMBBR 0x59C2  // amber-brown — empty step cell border
#define C_MGND  0x3009  // dark magenta — accent step cell background

Adafruit_ST7789 tft = Adafruit_ST7789(&SPI, TFT_CS, TFT_DC, TFT_RST);

// =====================================================================
// NOTE FREQUENCY TABLE
// =====================================================================
// Placed in RAM (see updateAudio comment) — avoids XIP contention with core 1's SPI traffic
const uint16_t __not_in_flash("audiotables") noteFreq[60] = {
  274,291,308,326,346,366,388,411,436,461,489,518,
  549,581,616,652,691,732,776,822,871,923,978,1036,
  1097,1163,1232,1305,1383,1465,1552,1644,1742,1845,1955,2071,
  2195,2325,2463,2610,2765,2930,3104,3288,3484,3691,3910,4143,
  4389,4650,4927,5220,5530,5859,6207,6577,6968,7382,7821,8286,
};

// =====================================================================
// WAVETABLES
// =====================================================================
const uint8_t __not_in_flash("audiotables") sinetable[256] = {
  127,130,133,136,139,142,145,148,151,154,157,160,163,166,169,172,
  175,178,181,184,186,189,192,194,197,200,202,205,207,209,212,214,
  216,218,221,223,225,227,229,230,232,234,235,237,239,240,241,243,
  244,245,246,247,248,249,250,250,251,252,252,253,253,253,253,253,
  254,253,253,253,253,253,252,252,251,250,250,249,248,247,246,245,
  244,243,241,240,239,237,235,234,232,230,229,227,225,223,221,218,
  216,214,212,209,207,205,202,200,197,194,192,189,186,184,181,178,
  175,172,169,166,163,160,157,154,151,148,145,142,139,136,133,130,
  127,123,120,117,114,111,108,105,102,99,96,93,90,87,84,81,
  78,75,72,69,67,64,61,59,56,53,51,48,46,44,41,39,
  37,35,32,30,28,26,24,23,21,19,18,16,14,13,12,10,
  9,8,7,6,5,4,3,3,2,1,1,0,0,0,0,0,
  0,0,0,0,0,0,1,1,2,3,3,4,5,6,7,8,
  9,10,12,13,14,16,18,19,21,23,24,26,28,30,32,35,
  37,39,41,44,46,48,51,53,56,59,61,64,67,69,72,75,
  78,81,84,87,90,93,96,99,102,105,108,111,114,117,120,123
};

const uint8_t __not_in_flash("audiotables") noisetable[64] = {
  232,175,188,102,142,3,70,116,17,139,22,155,54,118,84,22,
  251,228,160,233,30,32,6,125,16,216,122,189,95,232,135,205,
  181,97,90,80,76,170,0,4,123,183,46,163,185,40,47,208,
  145,67,219,87,74,140,213,10,72,51,29,142,230,63,204,123
};

const uint8_t __not_in_flash("audiotables") compressortable[256] = {
  0,1,3,5,7,9,10,12,14,16,18,19,21,23,25,27,
  28,30,32,34,36,37,39,41,43,45,46,48,50,52,54,55,
  57,59,61,63,64,66,68,70,72,73,75,77,79,81,82,84,
  86,88,90,91,93,95,97,99,100,102,104,106,108,109,111,113,
  115,117,118,120,122,124,126,127,129,131,133,135,136,138,140,142,
  144,145,147,149,151,153,154,156,158,160,162,163,165,167,169,171,
  172,174,176,178,180,181,183,185,187,189,190,192,194,196,198,199,
  201,203,205,207,208,210,212,214,216,217,219,221,223,225,226,228,
  228,228,228,228,228,229,229,229,229,229,230,230,230,230,230,231,
  231,231,231,231,232,232,232,232,233,233,233,233,233,234,234,234,
  234,234,235,235,235,235,235,236,236,236,236,237,237,237,237,237,
  238,238,238,238,238,239,239,239,239,239,240,240,240,240,241,241,
  241,241,241,242,242,242,242,242,243,243,243,243,243,244,244,244,
  244,245,245,245,245,245,246,246,246,246,246,247,247,247,247,247,
  248,248,248,248,249,249,249,249,249,250,250,250,250,250,251,251,
  251,251,251,252,252,252,252,252,253,253,253,253,254,254,254,255
};

// Per-sound pot mapping ranges [CUT_LO, CUT_HI, RES_LO, RES_HI]
// Resonance smoothing curve — applied to positive gResonance values only.
// Maps linear 0-508 through a power-1.6 curve so the resonance peak builds
// gradually from zero instead of jumping abruptly at the midpoint of the pot.
// Negative gResonance (damping side) is left linear and unchanged.
// Usage: if (gResonance > 0) gResonance = resCurve[gResonance];
const uint16_t __not_in_flash("audiotables") resCurve[512] = {
    0,  0,  0,  0,  0,  0,  0,  1,  1,  1,  1,  1,  1,  1,  2,  2,
    2,  2,  2,  3,  3,  3,  3,  4,  4,  4,  4,  5,  5,  5,  5,  6,
    6,  6,  7,  7,  7,  8,  8,  8,  9,  9,  9, 10, 10, 11, 11, 11,
   12, 12, 12, 13, 13, 14, 14, 14, 15, 15, 16, 16, 17, 17, 18, 18,
   18, 19, 19, 20, 20, 21, 21, 22, 22, 23, 23, 24, 24, 25, 25, 26,
   26, 27, 27, 28, 29, 29, 30, 30, 31, 31, 32, 32, 33, 34, 34, 35,
   35, 36, 37, 37, 38, 38, 39, 40, 40, 41, 41, 42, 43, 43, 44, 45,
   45, 46, 47, 47, 48, 48, 49, 50, 50, 51, 52, 53, 53, 54, 55, 55,
   56, 57, 57, 58, 59, 60, 60, 61, 62, 62, 63, 64, 65, 65, 66, 67,
   68, 68, 69, 70, 71, 71, 72, 73, 74, 74, 75, 76, 77, 78, 78, 79,
   80, 81, 82, 82, 83, 84, 85, 86, 86, 87, 88, 89, 90, 91, 91, 92,
   93, 94, 95, 96, 97, 97, 98, 99,100,101,102,103,104,104,105,106,
  107,108,109,110,111,112,112,113,114,115,116,117,118,119,120,121,
  122,123,124,125,125,126,127,128,129,130,131,132,133,134,135,136,
  137,138,139,140,141,142,143,144,145,146,147,148,149,150,151,152,
  153,154,155,156,157,158,159,160,161,162,163,164,165,167,168,169,
  170,171,172,173,174,175,176,177,178,179,180,182,183,184,185,186,
  187,188,189,190,191,193,194,195,196,197,198,199,200,201,203,204,
  205,206,207,208,209,211,212,213,214,215,216,218,219,220,221,222,
  223,225,226,227,228,229,230,232,233,234,235,236,238,239,240,241,
  243,244,245,246,247,249,250,251,252,254,255,256,257,258,260,261,
  262,263,265,266,267,268,270,271,272,274,275,276,277,279,280,281,
  282,284,285,286,288,289,290,291,293,294,295,297,298,299,301,302,
  303,305,306,307,309,310,311,313,314,315,317,318,319,321,322,323,
  325,326,327,329,330,331,333,334,336,337,338,340,341,342,344,345,
  347,348,349,351,352,354,355,356,358,359,361,362,363,365,366,368,
  369,370,372,373,375,376,378,379,380,382,383,385,386,388,389,391,
  392,393,395,396,398,399,401,402,404,405,407,408,410,411,412,414,
  415,417,418,420,421,423,424,426,427,429,430,432,433,435,436,438,
  439,441,442,444,446,447,449,450,452,453,455,456,458,459,461,462,
  464,465,467,469,470,472,473,475,476,478,480,481,483,484,486,487,
  489,491,492,494,495,497,498,500,502,503,505,506,508,508,508,508,
};

const int soundRange[11][4] = {
  {718,200,  70,1020},   // 0  SAW+LPF
  {670,260,  80,670},    // 1  SQR+LPF
  {670,0,    0,1020},    // 2  SINE+LPF
  {670,270,  80,1020},   // 3  NOISE+LPF
  {1020,250, 0,1020},    // 4  CSAW  — CUT reversed
  {1023,0,   0,1023},    // 5  CSQR  — CUT reversed
  {1020,600, 0,1020},    // 6  CSIN  — CUT reversed
  {1023,0,   1023,0},    // 7  NOISE+COMB
  {1023,0,   0,1023},    // 8  PWM
  {1023,0,   0,1023},    // 9  SUB SQUARE — RES=filter resonance(reversed), CUT=sub mix
  {0,1023,   0,1023},    // 10 WAVESHAPE
};

int restrictValue(int val, int mn, int mx) {
  long temp = mx - mn;
  temp *= (val < 0 ? 0 : (val > 1023 ? 1023 : val));
  temp /= 1023;
  return (int)(temp + mn);
}

// =====================================================================
// SYNTHESIS STATE
// =====================================================================
volatile uint16_t gFreq      = 287;
volatile uint16_t gTarget    = 287;
volatile int32_t  gFreqFP    = 287 << 8;  // 8.8 fixed-point; gFreq = gFreqFP >> 8
volatile int32_t  gGlideStep = 0;
volatile bool     gGlide     = false;
volatile bool     gPorta     = false;     // portamento — reserved for future use
volatile uint8_t  gPortaSpeed= 4;

volatile int16_t  gCutoff           = 64;
volatile int16_t  gCutoffDisplay    = 64;   // 0-255 for bar display (raw pot, no envelope)
volatile int16_t  gResonance        = 0;
volatile int16_t  gResonanceDisplay = 512;  // 0-1023 for bar display (512 = mid)
volatile int16_t  gVolSub    = 500;
volatile int16_t  gEnvCutoff = 0;    // envelope filter boost — peaks on note-on, decays with DCY
volatile int16_t  gEnvRes    = 0;    // accent resonance envelope boost — peaks on accented note-on, decays with DCY
volatile bool     gAccentActive = false;  // true while the current note's accent envelope is decaying
volatile uint8_t  gSound     = 0;
volatile uint8_t  gEffect    = 0;
volatile int16_t  gDecaySpeed= 2;
int16_t  lastDecaySpeed = 2;  // frozen gDecaySpeed value while accentEditMode is active
volatile uint32_t gLastStepMs= 0;

static uint16_t cnt = 0;
volatile int16_t filtA = 0;
volatile int16_t filtB = 0;
static uint8_t   combBuf[256];
static uint8_t   combPtr = 0;

volatile uint32_t lfoPos   = 0;
volatile int      lfoOffset= 0;
volatile uint8_t  phaseSw  = 128;

volatile uint16_t vFreq[8];
volatile uint16_t vCnt[8];
volatile uint16_t subFreq = 144;  // Sub Square oscillator frequency = gFreq/2 (sound 9)
volatile uint16_t subMix  = 0;    // Sub Square mix balance 0-1023 (sound 9)
static uint16_t subCnt = 0;       // Sub Square phase accumulator
volatile uint8_t  numV  = 1;
volatile uint8_t  volStd= 128;
volatile uint8_t  volClp= 128;

const int8_t __not_in_flash("audiotables") arpeggio[4][4] = {
  {0, 4, 7, 12},
  {0, 3, 7, 12},
  {0, 4, 7, 11},
  {0, 3, 6,  9},
};

// =====================================================================
// SEQUENCER
// =====================================================================
#define NUM_STEPS 16

struct Step {
  uint8_t note;
  bool    active;
  bool    accent;
  bool    glide;
  uint8_t effect;
};

struct Sequencer {
  Step    steps[NUM_STEPS];
  uint8_t origNote[NUM_STEPS];  // working notes — rootNote transposed to current key
  uint8_t rootNote[NUM_STEPS];  // permanent store — always relative to key=C, never mutated
  uint8_t cur;
  uint8_t len;
  bool    running;
  uint16_t tempo;
  uint32_t interval;
  uint32_t lastUs;
  uint8_t  octave;
  uint8_t  sound;
  int8_t   trans;
  uint8_t  arpPos;
  uint8_t  key;
  uint8_t  scale;
  uint8_t  algo;
};

// =====================================================================
// PRESET PATTERNS  (8 baked-in acid riffs, absolute semitones key=C)
// =====================================================================
#define NUM_PRESETS 8
struct PresetPattern {
  uint8_t note[16];
  uint8_t flags[16];   // bit0=active, bit1=accent
  uint8_t glide[16];
  uint8_t effect[16];
};
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
void loop() {
  audioHook();
}

// =====================================================================
// CORE 1 — Display handler
// All SPI/TFT calls happen here, never in core 0.
// =====================================================================
void setup1() {
  rp2040.fifo.pop();  // wait for core 0 setup to complete
}

void loop1() {
  // Fill drum buffer first — always top priority, must not starve
  bmFillDrumBuffer();

  // Handle mode switch signal from core 0. Drain the FIFO so any queued
  // duplicate/stale messages don't cause repeated fillScreen() calls that
  // leave the display blank for multiple loop1() passes — keep only the
  // most recent message.
  uint32_t fifoMsg;
  bool gotSwitch = false;
  uint32_t lastMsg = 0;
  while (rp2040.fifo.pop_nb(&fifoMsg)) {
    if (fifoMsg == 2 || fifoMsg == 3) { gotSwitch = true; lastMsg = fifoMsg; }
  }
  if (gotSwitch) {
    tft.fillScreen(0x0000);
    bmFillDrumBuffer();  // refill after screen clear (slow)
    if (lastMsg == 2) {
      bmFullDirty = true;
      bmDoDraw();
    } else {
      ui.fullDirty = false;  // consume the flag; drawMain() below does the work
      drawMain();
    }
    bmFillDrumBuffer();  // refill after draw
    return;
  }

  if (bmMode) {
    bmDoDraw();          // handles all dirty flags including bmDrumsDirty
    bmFillDrumBuffer();
    return;
  }

  if (saveCommit) {
    saveCommit = false;
    EEPROM.commit();
  }

  // Save progress bar — only redraws when pct changes (drawSaveProgress is self-throttled)
  if (ui.slotProgressShow) {
    drawSaveProgress(ui.slotProgress);
  }
  // Save/load confirmation banner
  else if (ui.slotOverlay) {
    drawSlotOverlay();
  }
  else if (ui.fullDirty || ui.editDirty || ui.funcDirty ||
      ui.cellsDirty || ui.barDirty || ui.valDirty || ui.infoDirty) {
    ui.dirty = false;
    doDraw();
  } else {
    // Cursor tracking during playback
    uint32_t now1 = millis();
    if (seq.running && !fxAssignMode) {
      uint32_t msSinceStep = now1 - gLastStepMs;
      if (msSinceStep > 40 && msSinceStep < 80 && (now1 - ui.lastMs) > 60) {
        ui.lastMs = now1;
        static uint8_t prevCurDisp = 255;
        if (prevCurDisp != seq.cur) {
          if (prevCurDisp != 255) drawStepCell(prevCurDisp);
          drawStepCell(seq.cur);
          prevCurDisp = seq.cur;
        }
      }
    }
  }
  delay(4);
}

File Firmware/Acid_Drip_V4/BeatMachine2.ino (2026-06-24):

/*
 * =====================================================================
 *  BEAT MACHINE 2  —  Acid Drip RP2040, standalone sketch
 *  Audio engine: DrumKid (Matt Bradshaw), ported by Marcus / lonesoulsurfer
 * =====================================================================
 *
 * SCREEN LAYOUT (320×240 landscape):
 *   y=0-11    Slot dots  (4 circles above pads 3-6)
 *   y=12-21   Step grid  (5 drum rows × 2px)
 *   y=24-43   Value strip
 *   y=46-83   Pad row 0  (beats 1-8, square pads)
 *   y=85-122  Pad row 1  (beats 9-16, square pads)
 *   y=125-140 FUNC label strip
 *   y=143-166 Pot bars
 *   y=170-239 Info strip
 *
 * DRUM EDIT (normal mode):
 *   Hold pad 1-5 (kick/hat/snare/rim/tom) while turning pots:
 *     CUT = pitch   RES = crop/length   DCY = volume
 *   Pot pickup prevents jumps on entry.
 *   Resets to defaults on pattern change.
 *   Saved/loaded with slots.
 *
 * FUNC MODE (pads 7+8):
 *   PTCH=global pitch  DRIV=drive/saturation  FILT=bipolar DJ filter
 *   CHNC=per-hit drop chance  HMNZ=velocity humanize  SWNG=16th swing
 *   ACNT=accent depth  FILL=procedural fill engine
 *
 * SAVE/LOAD: hold pads 7+8, then tap/hold pads 3-6
 * RESET:     hold pads 1+2 for 1 second
 * =====================================================================
 */


// =====================================================================
// BEAT MACHINE 2 — Tab for Acid Drip V4
// Place this file in the same folder as Acid_Drip_V4.ino
// =====================================================================

bool bmMode = false;
bool bmAlarmStarted = false;
bool bmPlayChanged = false;  // signals V4 to sync acid play state
byte bmDrumPos  = 0;   // persistent drum pattern position (0-31)
// ── Fill engine ──────────────────────────────────────────────────────
// Procedural fills take over the last 4-8 steps before a boundary (length
// scales with frequency). Density accelerates into a kick+openhat landing.
byte     bmFillMode = 0;   // 0=off  1=every 1 bar  2=every 2 bars  3=every 4 bars
byte     bmFillType = 0;   // 0=HATS  1=CLAP  2=SNARE  3=KIT (tom descent -> snare)
uint16_t bmAbsStep  = 0;   // free-running step counter (fill phase), resets on play
bool     bmWasInFill = false;   // was the previous step inside a fill? (for landing)
// Each fill type's LEAD voice (HATS=hihat CLAP=clap SNARE=snare KIT=tom) has its
// own locked sound (bmFillPitch/Len/Vol — declared with the drum arrays below,
// since they need NUM_DRUMS). Applied during the fill, restored after.
uint8_t  bmFillTouched = 0;     // bitmask of voices given fill sound (need restore)
// Density acceleration: schedule one 32nd-note in-between hit, fired from
// bmUpdateControl. Same mechanism as the old double-time, but fill-only.
bool     bmFillDblPending = false;
uint32_t bmFillDblDueUs   = 0;
byte     bmFillDblDrum     = 0;
uint8_t  bmFillDblGain     = 0;   // final gain for the scheduled 32nd (vol already folded in)
uint32_t bmHumanizeJitUs = 0;     // max late jitter (us) at the current HMNZ setting
// Pot pickup for in-fill drum editing: on a target-drum switch all three
// pots lock, each releasing only once physically moved (movement-gated),
// so a returned-to drum keeps its own values until you touch a pot.
int8_t   bmFillEditDrum = -1;
bool     bmFillPotLock[3] = {true,true,true};   // 0=CUT/pitch 1=RES/len 2=DCY/vol
uint8_t  bmFillPotRef[3]  = {0,0,0};            // pot position captured at lock
#define NUM_DRUMS 8
// HMNZ micro-timing: each pattern hit can be nudged late independently, fired
// from bmUpdateControl (same micros() polling as swing/fill schedulers).
bool     bmHitPend[NUM_DRUMS]  = {};
uint32_t bmHitDueUs[NUM_DRUMS] = {};
uint8_t  bmHitGain[NUM_DRUMS]  = {};
uint32_t bmLastFlashDraw = 0;
bool bmLastFlashState[NUM_DRUMS] = {};
PWMAudio bmPWM(2);  // drum audio on GP2, DMA-driven
bool bmTriggered[NUM_DRUMS] = {};
// Per-hit playback gain = (drum volume * velocity) >> 8, computed at
// trigger time so the audio loop stays at one multiply per voice.
// volatile: written on core 0 (trigger), read+decremented on core 1 (choke fade).
volatile uint8_t bmGain[NUM_DRUMS] = {};
volatile bool bmHatChoke = false;   // closed hat fired → fade out open hat
volatile uint8_t bmLastVel = 0;     // velocity of most recent hit (HMNZ diagnostic)
// Per-voice decay envelope: bmEnv is 8.8 fixed-point gain seeded with
// bmGain<<8 at trigger, multiplied by bmEnvM every sample on core 1.
// bmEnvM 65535 = hold (no decay); smaller = faster exponential decay.
volatile uint16_t bmEnv[NUM_DRUMS]  = {};
uint16_t          bmEnvM[NUM_DRUMS] = {65535,65535,65535,65535,65535,65535,65535,65535};


#include <Sample.h>
#include <mozzi_rand.h>
#include <PWMAudio.h>
#include "beats.h"
#include "sample0.h"
#include "sample1.h"
#include "sample2.h"
#include "sample3.h"
#include "sample4.h"
#include "sample5.h"
#include "sample6.h"
#include "sample7.h"

// ── Pins ─────────────────────────────────────────────────────────────
#define POT_CUT  26
#define POT_RES  28
#define POT_DECAY 27

#define BM_PAD_FUNC_A  6
#define BM_PAD_FUNC_B  7

// ── Display ───────────────────────────────────────────────────────────
#define SW  320
#define SH  240

#define BM_DOTS_Y   0
#define BM_DOTS_H  12
#define BM_GRID_Y  14
#define BM_GRID_H  16
#define BM_VS_Y    34    // value strip
#define BM_VS_H    20
#define BM_DS_Y    54    // drum strip — directly under value strip
#define BM_DS_H    16
#define BM_PAD_BW  38    // square pads
#define BM_PAD_BH  38
#define BM_PAD_SP   1
#define BM_PAD_SX   3
#define BM_PAD_R0  72    // pad row 0
#define BM_PAD_R1 111    // pad row 1
#define BM_LBL_Y  152    // func label strip
#define BM_LBL_H   16
#define BM_BAR_Y  170    // pot bars
#define BM_BAR_P    9
#define BM_BAR_BH   6
#define BM_IS_Y   200    // info strip


// ── Samples ───────────────────────────────────────────────────────────
Sample<sample0_NUM_CELLS, AUDIO_RATE> bms0(sample0_DATA);
Sample<sample1_NUM_CELLS, AUDIO_RATE> bms1(sample1_DATA);
Sample<sample2_NUM_CELLS, AUDIO_RATE> bms2(sample2_DATA);
Sample<sample3_NUM_CELLS, AUDIO_RATE> bms3(sample3_DATA);
Sample<sample4_NUM_CELLS, AUDIO_RATE> bms4(sample4_DATA);
Sample<sample5_NUM_CELLS, AUDIO_RATE> bms5(sample5_DATA);
Sample<sample6_NUM_CELLS, AUDIO_RATE> bms6(sample6_DATA);
Sample<sample7_NUM_CELLS, AUDIO_RATE> bms7(sample7_DATA);
// Looping disabled — samples play once per trigger, silence between hits
// Without this, samples loop continuously causing a constant hum

// ── Per-drum defaults ─────────────────────────────────────────────────
// pitch: 128 = natural speed (1.0x); 0=0.25x; 255=4.0x
// crop:  255 = full sample length
#define BM_DEF_DRUM_PITCH  128  // 128 = pot centre = natural speed
#define BM_DEF_DRUM_CROP   255
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
